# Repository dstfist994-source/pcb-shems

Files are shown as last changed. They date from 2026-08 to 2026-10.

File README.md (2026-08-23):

# Industrial IoT Smart Edge Device & Isolated Energy Controller

**A robust, mixed-signal hardware platform designed for AC mains energy monitoring, power conversion, and isolated load control. Engineered with high-voltage clearance, discrete signal shifting, and inductive load protection.**

---

## 📖 Overview

This **Smart Edge Node** is an industrial/home energy monitoring and switching board that bridges high-voltage AC mains power with low-voltage microcontroller logic. Designed with a focus on **analog hardware reliability**, **power distribution**, and **galvanic isolation**, the design integrates on-board AC-DC regulated conversion, discrete MOSFET level translation, and an optoisolated transistor relay driver with flyback suppression.

The system utilizes an **ESP8266 (Lolin)** for edge processing and software-driven UART communication with a **PZEM-004T** metering module, enabling real-time telemetry publication over Wi-Fi (MQTT/HTTP) while safely controlling heavy AC electrical loads.

---

## 📸 Visuals

| **3D PCB Render** | **PCB Layout & Routing** | **Hardware Schematic** |
|:---:|:---:|:---:|
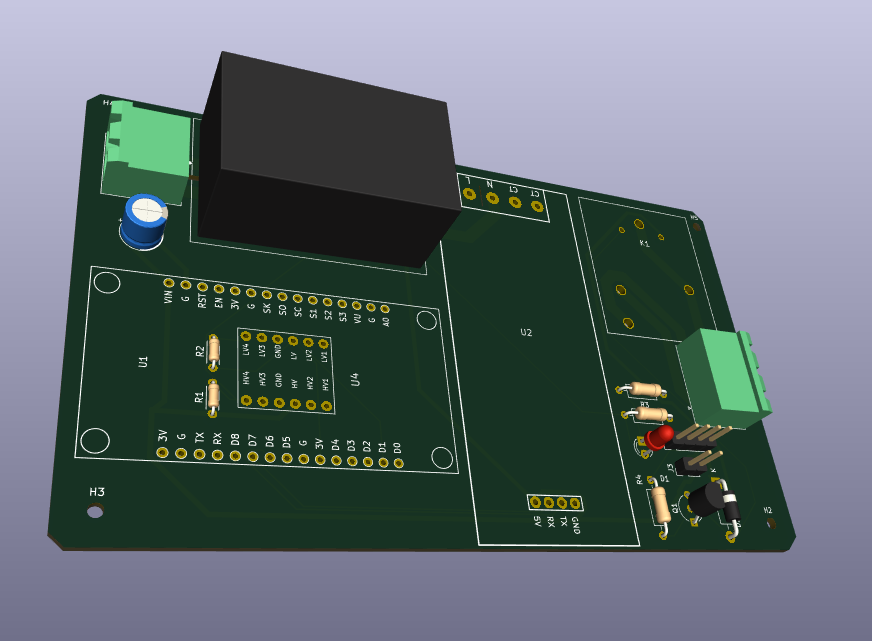
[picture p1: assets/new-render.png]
3D Render
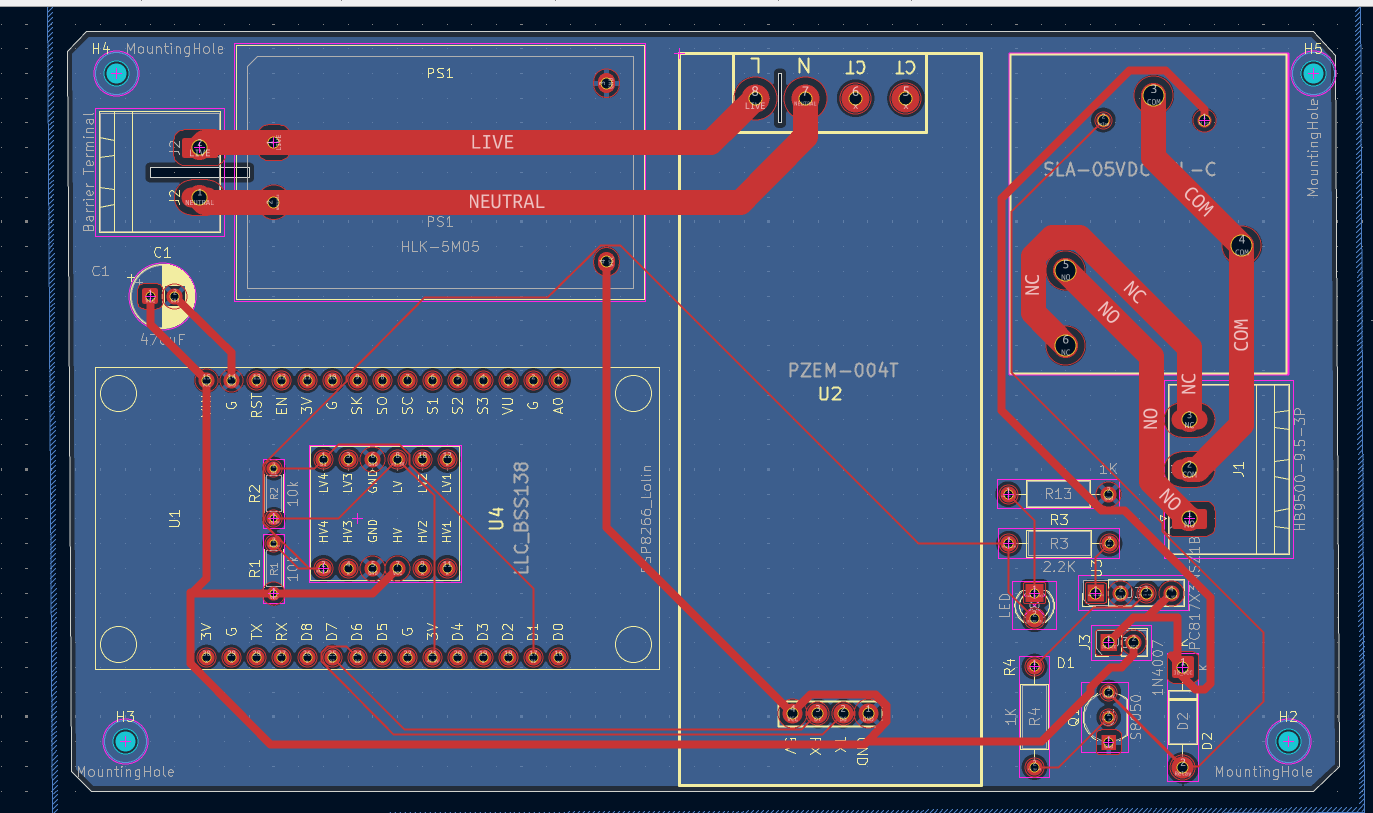
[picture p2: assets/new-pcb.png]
PCB Layout
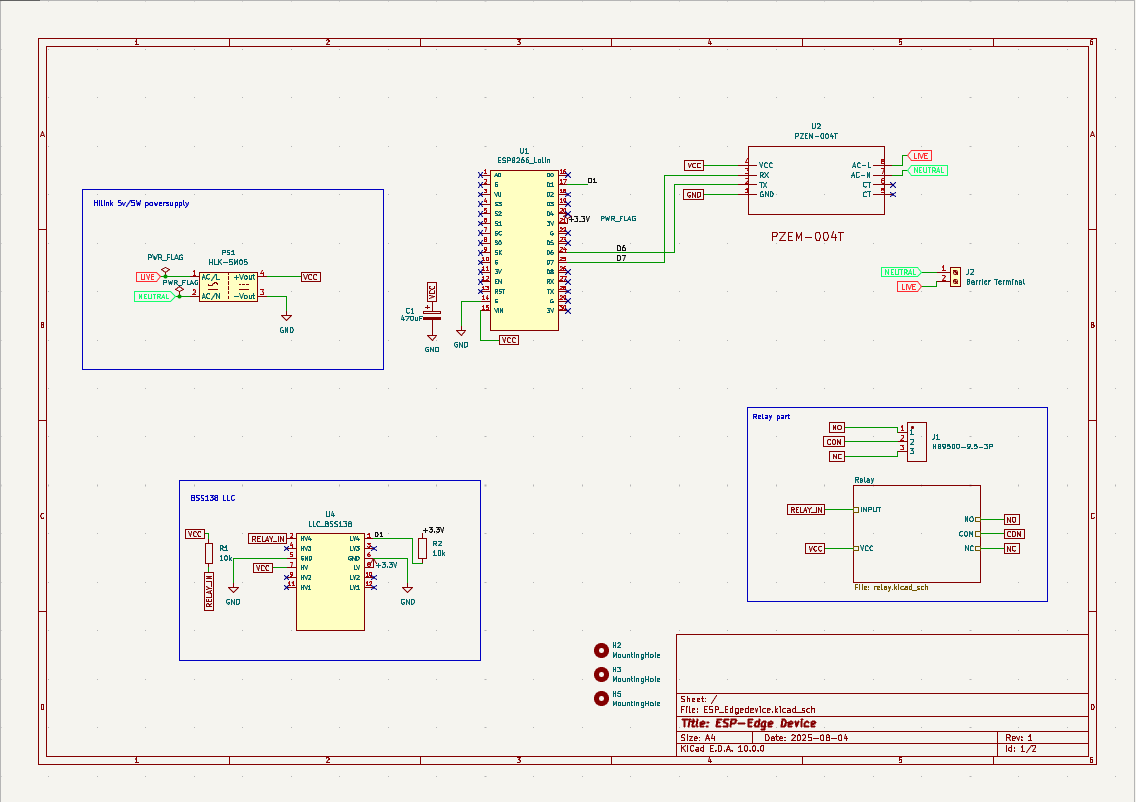
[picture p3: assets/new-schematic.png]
Schematic
|  |  |  |
| *KiCad 3D Ray-traced Board View* | *2-Layer Trace & High-Voltage Clearance* | *System Schematic Architecture* |

---

## ⚡ Hardware & Analog Engineering Highlights

### 1. Power Management & Bulk Decoupling
* **Integrated AC-DC Conversion:** Employs an on-board **Hi-Link HLK-5M05** module to convert $230\text{V AC}$ mains input directly down to a regulated $5\text{V DC}$ supply rail.
* **Transient Suppression & Ripple Filtering:** Features a high-capacity **$470\ \mu\text{F}$ bulk electrolytic capacitor ($C1$)** across the $5\text{V}$ rail to absorb voltage dips, suppress power supply ripple, and maintain rail stability during high instantaneous relay coil pull-in current.

### 2. Level Translation & Signal Integrity
* **Bi-Directional MOSFET Level Shifting:** Incorporates a discrete **BSS138 N-channel MOSFET Logic Level Converter ($U4$)** to bridge the $3.3\text{V CMOS}$ GPIO output of the ESP8266 ($D1$) to the $5\text{V TTL}$ driver logic without overdriving MCU input pins.
* **Isolated UART Interface:** Software Serial UART interface ($D6/D7$) connecting to the **PZEM-004T** energy metering frontend for accurate RMS Voltage, Current, Active Power, Frequency, and Power Factor acquisition.

### 3. Optoisolated Load Control & Inductive Suppression
* **Galvanic Isolation Drive Stage:** High-voltage AC switching is completely isolated from low-voltage digital control using a **PC817 Optocoupler** and an **S8050 NPN transistor** driver stage.
* **Back-EMF Inductive Protection:** A **1N4007 flyback suppression diode ($D1$)** is placed across the **SLA-05VDC** relay coil to clamp high-voltage inductive spikes generated during coil de-energization, protecting switching silicon from overshoot breakdown.
* **Visual Diagnostics:** Integrated LED indicator with current-limiting resistor ($1\text{ k}\Omega$) for visual relay status feedback.

### 4. High-Voltage PCB Layout & Safety Design
* **Creepage & Clearance:** Wide physical clearance and routing separation between the $230\text{V}$ AC mains region (Live/Neutral) and low-voltage $5\text{V}/3.3\text{V}$ DC signal planes to prevent electrical arcing.
* **Current-Handling Traces:** Heavy trace widths utilized on AC Live/Neutral routing and high-current relay switching paths to minimize trace impedance, drop, and thermal rise under heavy electrical load.

---

## 🛠 Subsystem Breakdown

| Subsystem | Circuitry / Components | Function |
| :--- | :--- | :--- |
| **Power Supply** | HLK-5M05 + $470\ \mu\text{F}$ Capacitor | AC-DC Step-down ($230\text{V AC} \to 5\text{V DC}$) & Rail Filtering |
| **Microcontroller** | ESP8266 (Lolin V3 Footprint) | Wireless Telemetry, MQTT, SoftSerial UART, GPIO Control |
| **Logic Level Conversion** | BSS138 MOSFET Level Shifter ($U4$) | $3.3\text{V} \leftrightarrow 5\text{V}$ Logic Level Translation |
| **Relay Driver** | PC817 Optocoupler + S8050 NPN + 1N4007 Diode | Isolated coil energization & Back-EMF suppression |
| **AC Load Control** | SLA-05VDC High-Power Relay | Heavy AC Load ON/OFF Disconnect |
| **Energy Measurement** | PZEM-004T AC Sensor | High-accuracy RMS Voltage, Current, & Power Telemetry |

---

## 👨‍💻 Authors

- **Suvam Seth**
  *Power Engineering Student | PCB Design | Analog Electronics & Systems Design*

- **Sarin Sanyal**
  *Power Engineering Student | Analog & Mixed-Signal Circuit Design | Embedded Hardware | AI*

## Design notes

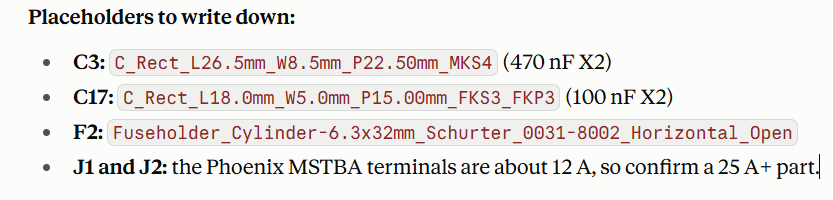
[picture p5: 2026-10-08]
assets/placeholders.png

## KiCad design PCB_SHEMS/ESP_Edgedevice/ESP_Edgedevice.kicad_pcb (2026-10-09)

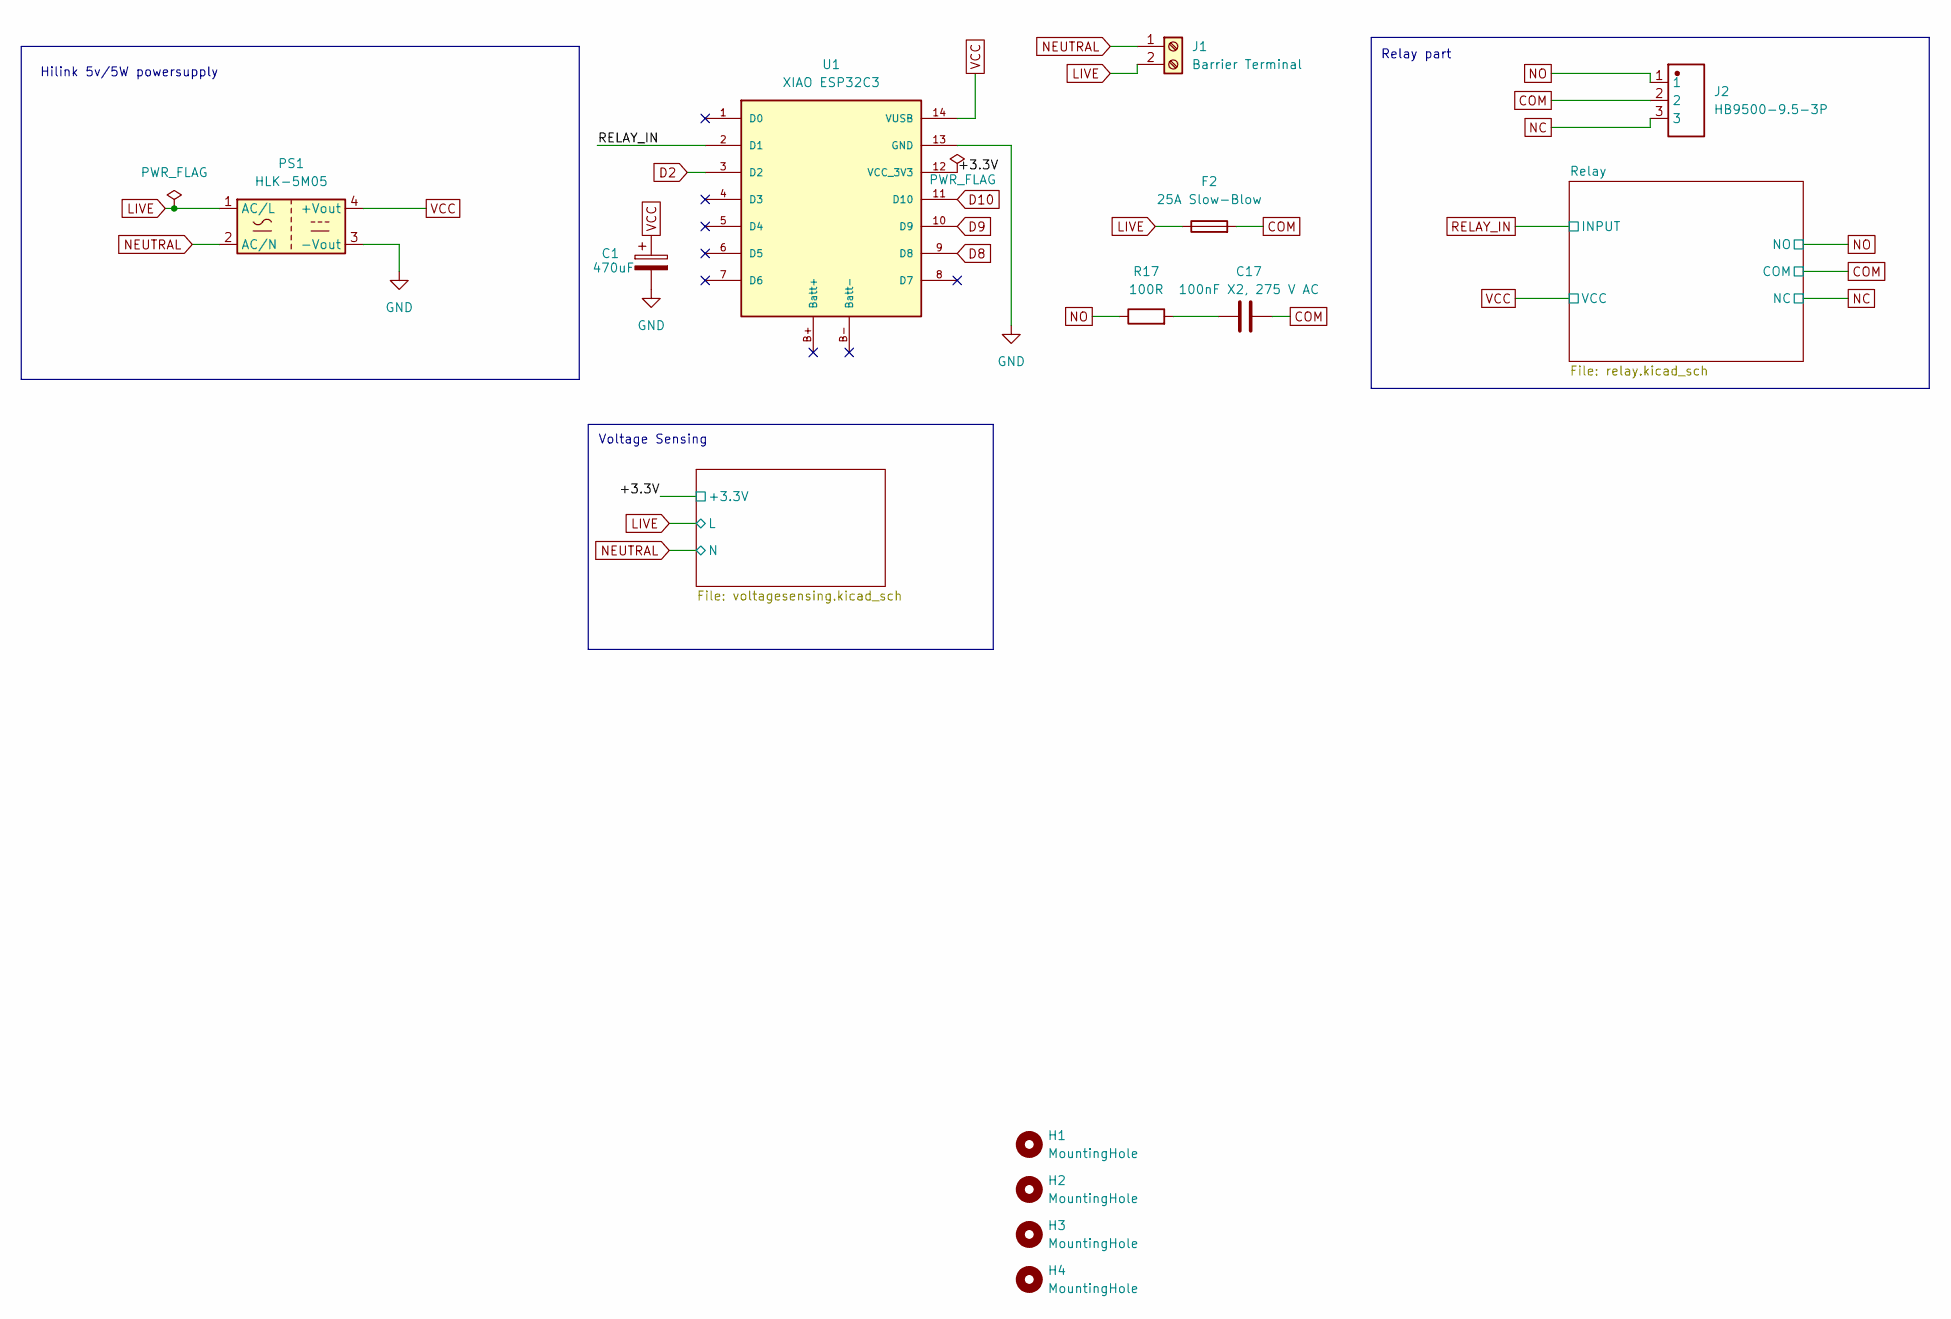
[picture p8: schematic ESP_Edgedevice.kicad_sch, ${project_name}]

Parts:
C1: 470uF; CP_Radial_D6.3mm_P2.50mm
C17: 100nF X2, 275 V AC; C_Rect_L18.0mm_W5.0mm_P15.00mm_FKS3_FKP3
F2: 25A Slow-Blow; Fuseholder_Cylinder-6.3x32mm_Schurter_0031-8002_Horizontal_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
H1, H2, H3, H4: MountingHole; MountingHole_2.1mm
J1: Barrier Terminal; PhoenixContact_MSTBA_2,5_2-G_1x02_P5.00mm_Horizontal
J2: HB9500-9.5-3P; HB9500_9.5-3P; Manufacturer Part HB9500-9.5-3P
PS1: HLK-5M05; Converter_ACDC_Hi-Link_HLK-5Mxx
R17: 100R; R_Axial_DIN0309_L9.0mm_D3.2mm_P12.70mm_Horizontal
U1: XIAO ESP32C3; XIAO_Socket_W15.24

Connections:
/+3.3V: U1.12 (VCC_3V3); also elsewhere on the board
COM: C17.2, F2.2, J2.2; also elsewhere on the board
D2: U1.3 (D2); also elsewhere on the board
D8: U1.9 (D8); also elsewhere on the board
D9: U1.10 (D9); also elsewhere on the board
D10: U1.11 (D10); also elsewhere on the board
GND: C1.2, PS1.3 (-Vout), U1.13 (GND); also elsewhere on the board
LIVE: F2.1, J1.2, PS1.1 (AC/L); also elsewhere on the board
NC: J2.3; also elsewhere on the board
NEUTRAL: J1.1, PS1.2 (AC/N); also elsewhere on the board
NO: J2.1, R17.1; also elsewhere on the board
unnamed: C17.1, R17.2
RELAY_IN: U1.2 (D1); also elsewhere on the board
VCC: C1.1, PS1.4 (+Vout), U1.14 (VUSB); also elsewhere on the board

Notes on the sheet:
Voltage Sensing
Relay part
Hilink 5v/5W powersupply

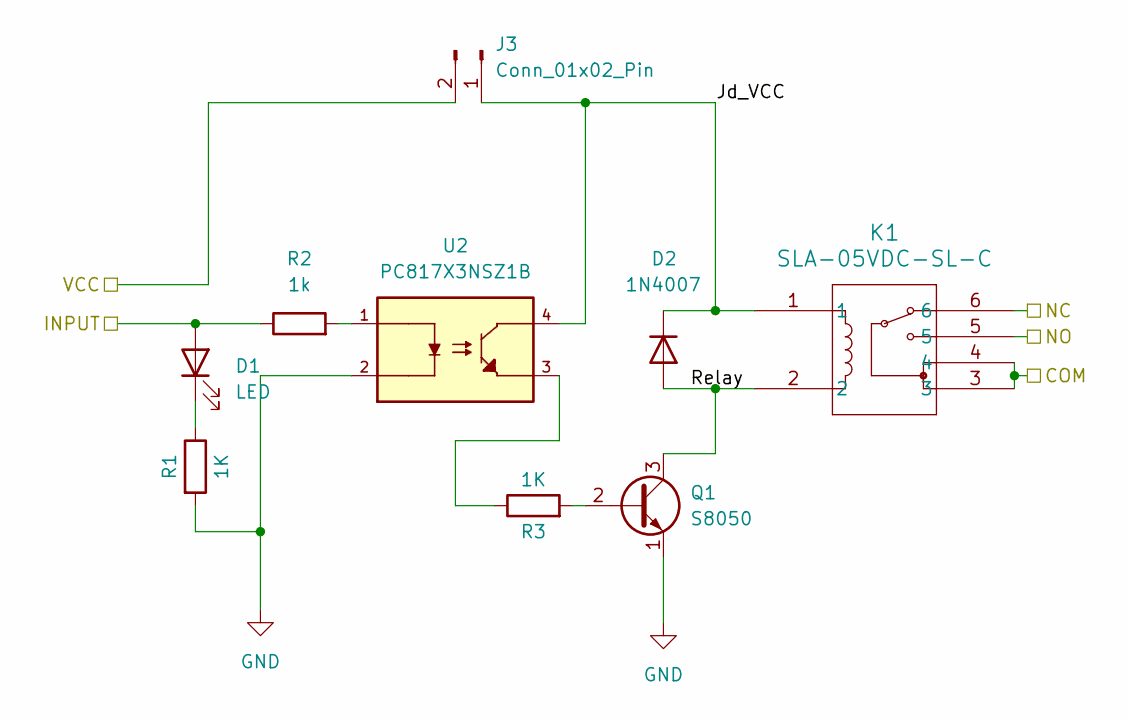
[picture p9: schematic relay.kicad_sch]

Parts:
D1: LED; LED_D3.0mm
D2: 1N4007; D_DO-41_SOD81_P10.16mm_Horizontal
J3: Conn_01x02_Pin; PinHeader_1x02_P2.54mm_Vertical
K1: SLA-05VDC-SL-C; RELAY-TH_SLA-XXVDC-XX-C
Q1: S8050; TO-92_Inline_Wide
R1, R3: 1K; R_1206_3216Metric
R2: 1k; R_1206_3216Metric
U2: PC817X3NSZ1B; DIP-4_W7.62mm; PARTREV October 7, 2016

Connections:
/Relay/Jd_VCC: D2.1 (K), J3.1, K1.1, U2.4
/Relay/Relay: D2.2 (A), K1.2, Q1.3 (C)
COM: K1.3, K1.4; also elsewhere on the board
GND: Q1.1 (E), R1.2, U2.2; also elsewhere on the board
NC: K1.6; also elsewhere on the board
NO: K1.5; also elsewhere on the board
unnamed: D1.1 (K), R1.1
unnamed: Q1.2 (B), R3.2
unnamed: R2.2, U2.1
unnamed: R3.1, U2.3
RELAY_IN: D1.2 (A), R2.1; also elsewhere on the board
VCC: J3.2; also elsewhere on the board

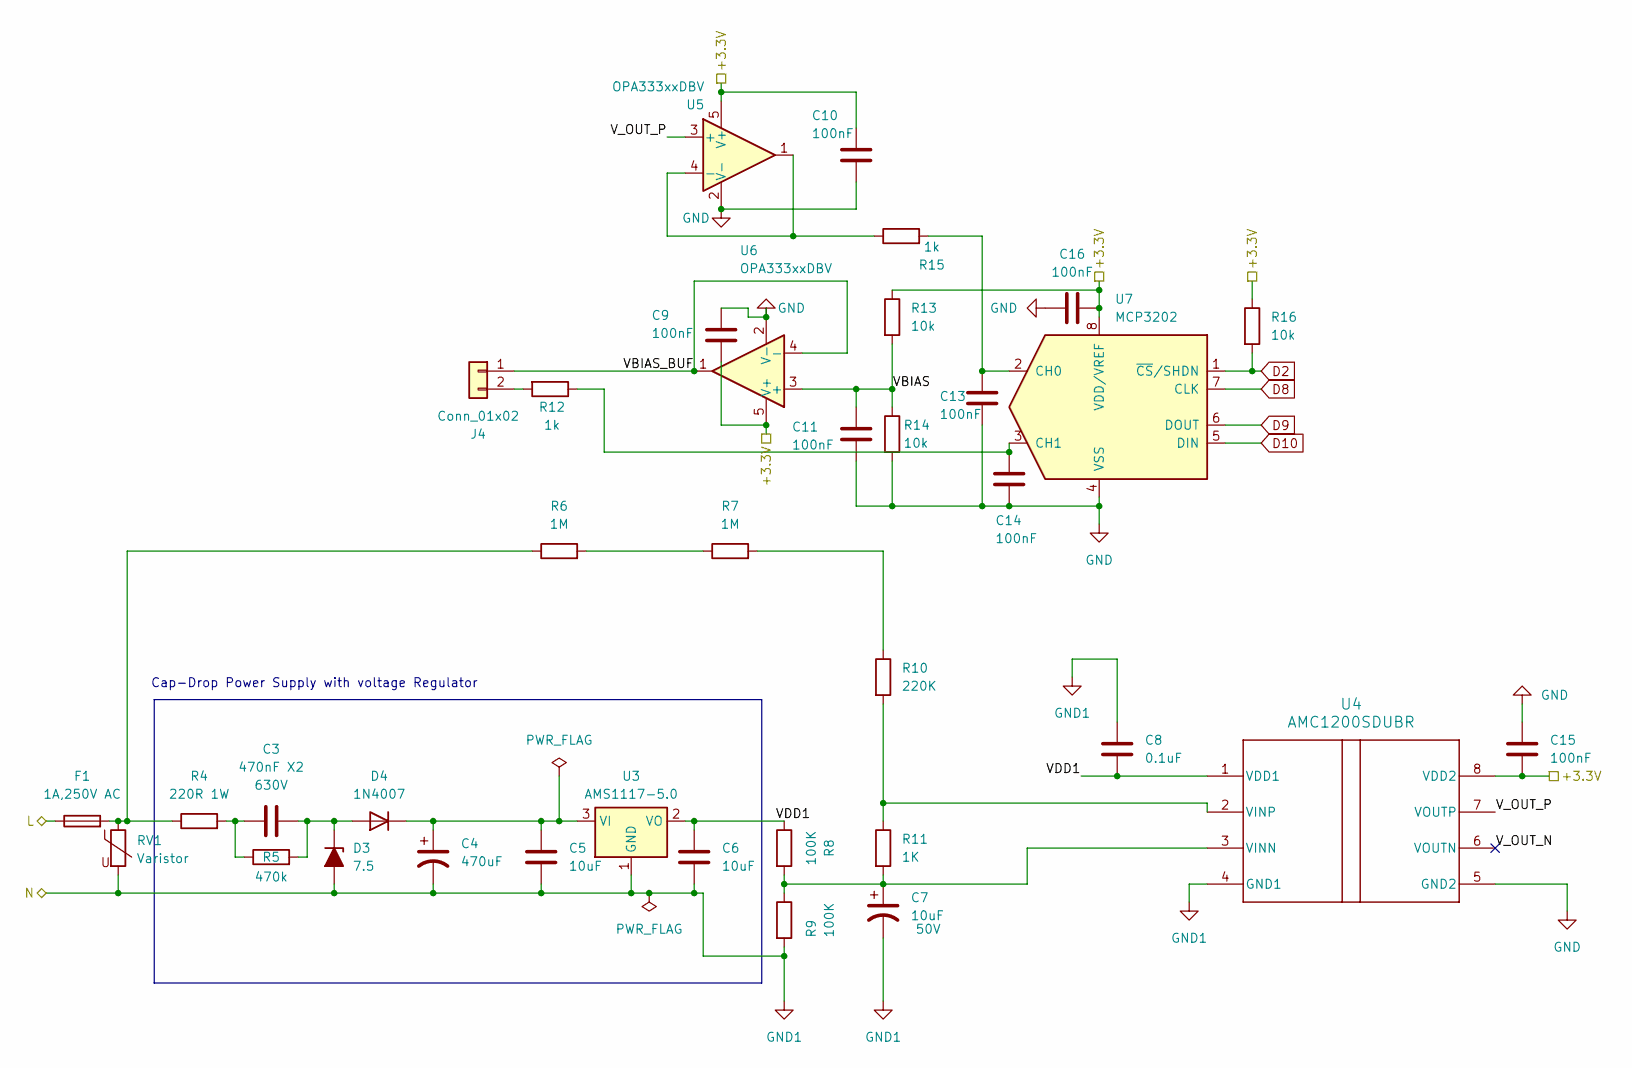
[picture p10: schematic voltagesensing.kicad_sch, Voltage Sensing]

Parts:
C3: 470nF X2; C_Rect_L26.5mm_W8.5mm_P22.50mm_MKS4; voltage 630V
C4: 470uF; CP_Radial_D10.0mm_P5.00mm
C5: 10uF; C_1206_3216Metric
C6: 10uF; CP_Radial_D5.0mm_P2.50mm
C7: 10uF; CP_Radial_D5.0mm_P2.50mm; Voltage 50V
C8: 0.1uF; C_1206_3216Metric
C9, C10, C11, C13, C14, C15, C16: 100nF; C_1206_3216Metric
D3: 7.5; D_MiniMELF
D4: 1N4007; D_DO-41_SOD81_P10.16mm_Horizontal
F1: 1A,250V AC; Fuseholder_Cylinder-5x20mm_Schurter_0031_8201_Horizontal_Op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
J4: Conn_01x02; PinHeader_1x02_P2.54mm_Vertical
R4: 220R 1W; R_Axial_DIN0414_L11.9mm_D4.5mm_P15.24mm_Horizontal
R5: 470k; R_Axial_DIN0207_L6.3mm_D2.5mm_P10.16mm_Horizontal
R6, R7: 1M; R_Axial_DIN0207_L6.3mm_D2.5mm_P10.16mm_Horizontal
R8, R9: 100K; R_1206_3216Metric
R10: 220K; R_1206_3216Metric
R11: 1K; R_1206_3216Metric
R12, R15: 1k; R_1206_3216Metric
R13, R14, R16: 10k; R_1206_3216Metric
RV1: Varistor; RV_Disc_D12mm_W4.2mm_P7.5mm
U3: AMS1117-5.0; SOT-223-3_TabPin2
U4: AMC1200SDUBR; DUB0008A-IPC_A
U5, U6: OPA333xxDBV; SOT-23-5
U7: MCP3202; TSSOP-8_4.4x3mm_P0.65mm

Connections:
/+3.3V: C9.1, C10.2, C15.2, C16.1, R13.1, R16.1, U4.8 (VDD2), U5.5 (V+), U6.5 (V+), U7.8 (VDD/VREF); also elsewhere on the board
/voltagesensing.kicad_sch/VBIAS: C11.1, R13.2, R14.1, U6.3 (+)
/voltagesensing.kicad_sch/VBIAS_BUF: J4.1, U6.1, U6.4 (-)
/voltagesensing.kicad_sch/VDD1: C6.1, C8.2, R8.1, U3.2 (VO), U4.1 (VDD1)
/voltagesensing.kicad_sch/V_OUT_N: U4.6 (VOUTN)
/voltagesensing.kicad_sch/V_OUT_P: U4.7 (VOUTP), U5.3 (+)
D2: R16.2, U7.1 (~CS/SHDN); also elsewhere on the board
D8: U7.7 (CLK); also elsewhere on the board
D9: U7.6 (DOUT); also elsewhere on the board
D10: U7.5 (DIN); also elsewhere on the board
GND: C9.2, C10.1, C11.2, C13.2, C14.2, C15.1, C16.2, R14.2, U4.5 (GND2), U5.2 (V-), U6.2 (V-), U7.4 (VSS); also elsewhere on the board
LIVE: F1.1; also elsewhere on the board
NEUTRAL: C4.2, C5.2, C6.2, C7.2, C8.1, D3.2 (A), R9.2, RV1.2, U3.1 (GND), U4.4 (GND1); also elsewhere on the board
unnamed: C3.1, R4.2, R5.1
unnamed: C3.2, D3.1 (K), D4.2 (A), R5.2
unnamed: C4.1, C5.1, D4.1 (K), U3.3 (VI)
unnamed: F1.2, R4.1, R6.1, RV1.1
unnamed: J4.2, R12.2
unnamed: R6.2, R7.1
unnamed: R7.2, R10.1
unnamed: C7.1, R8.2, R9.1, R11.2, U4.3 (VINN)
unnamed: R10.2, R11.1, U4.2 (VINP)
unnamed: R15.1, U5.1, U5.4 (-)
unnamed: C13.1, R15.2, U7.2 (CH0)
unnamed: C14.1, R12.1, U7.3 (CH1)

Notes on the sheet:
Cap-Drop Power Supply with voltage Regulator

Board: 2 copper layers, 57 parts (0 on the bottom side), 36 nets, no tracks yet.

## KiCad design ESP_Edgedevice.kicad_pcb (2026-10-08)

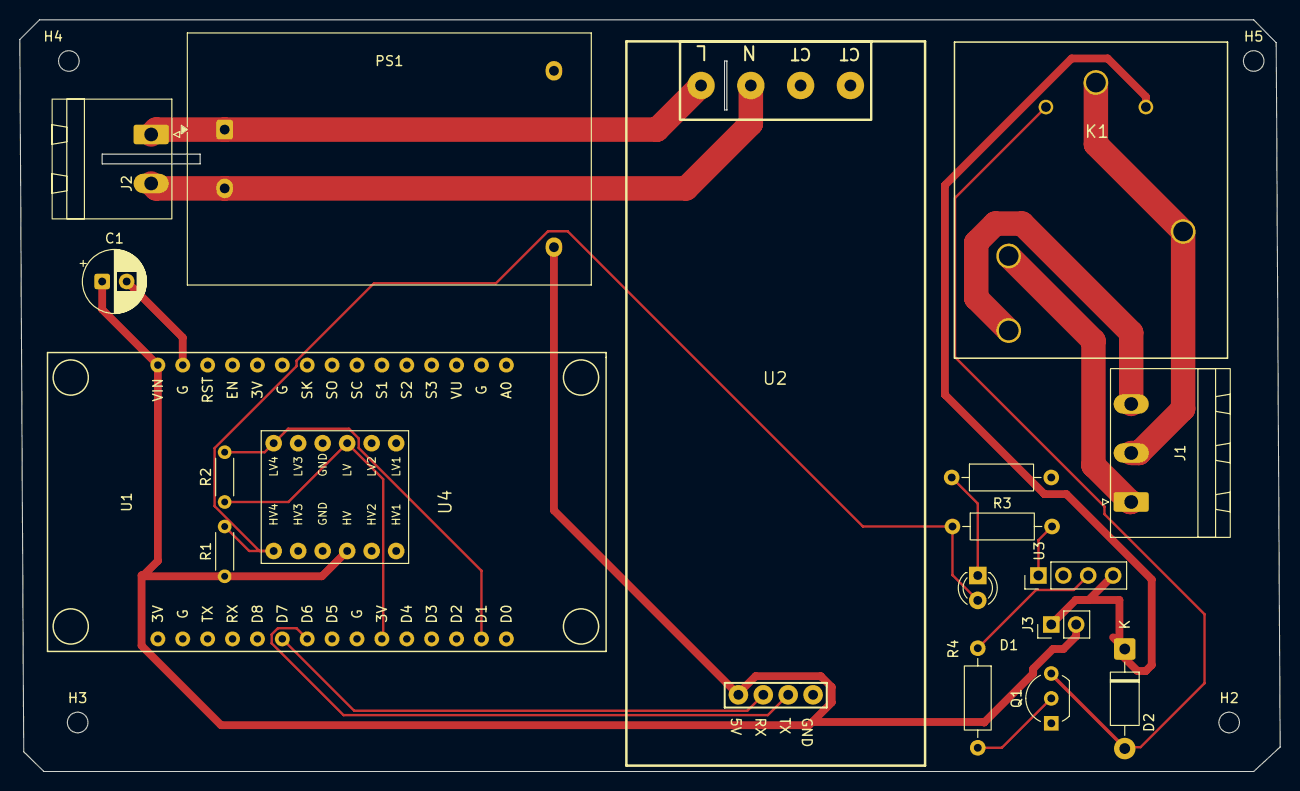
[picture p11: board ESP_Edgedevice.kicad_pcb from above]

Board: 2 copper layers, 128.6 x 76.7 mm, 22 parts (0 on the bottom side), 18 nets.

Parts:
C1: 470uF; CP_Radial_D6.3mm_P2.50mm
D1: LED; LED_D3.0mm
D2: 1N4007; D_DO-41_SOD81_P10.16mm_Horizontal
H2, H3, H4, H5: MountingHole; MountingHole_2.1mm
J1: HB9500-9.5-3P; PhoenixContact_MSTBA_2,5_3-G_1x03_P5.00mm_Horizontal
J2: Barrier Terminal; PhoenixContact_MSTBA_2,5_2-G_1x02_P5.00mm_Horizontal
J3: Conn_01x02_Pin; PinHeader_1x02_P2.54mm_Vertical
K1: SLA-05VDC-SL-C; K_SLA_C_NFR
PS1: HLK-5M05; Converter_ACDC_Hi-Link_HLK-5Mxx
Q1: S8050; TO-92_Inline_Wide
R1, R2: 10k; R_Axial_DIN0204_L3.6mm_D1.6mm_P5.08mm_Horizontal
R3: 2.2K; R_Axial_DIN0207_L6.3mm_D2.5mm_P10.16mm_Horizontal
R4, R13: 1K; R_Axial_DIN0207_L6.3mm_D2.5mm_P10.16mm_Horizontal
U1: ESP8266_Lolin; NodeMCU-LoLinV3
U2: PZEM-004T; PZEM-004T_V3
U3: PC817X3NSZ1B; PinHeader_1x04_P2.54mm_Vertical
U4: LLC_BSS138

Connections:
+3.3V: R2.1, U1.21 (3V), U4.8 (LV)
/D1: R2.2, U1.17 (D1), U4.1 (LV4)
/D6: U1.24 (D6), U2.2 (TX)
/D7: U1.25 (D7), U2.3 (RX)
/Relay/Jd_VCC: D2.1 (K), J3.1, K1.1, U3.4
/Relay/Relay: D2.2 (A), K1.2, Q1.3 (C)
COM: J1.2, K1.3, K1.4
GND: C1.2, PS1.3 (-Vout), Q1.1 (E), R13.2, U1.14 (G), U2.1 (GND), U3.2, U4.5 (GND), U4.6 (GND)
LIVE: J2.2, PS1.1 (AC/L), U2.8 (AC-L)
NC: J1.3, K1.6
NEUTRAL: J2.1, PS1.2 (AC/N), U2.7 (AC-N)
NO: J1.1, K1.5
unnamed: D1.1 (K), R13.1
unnamed: Q1.2 (B), R4.2
unnamed: R3.2, U3.1
unnamed: R4.1, U3.3
RELAY_IN: D1.2 (A), R1.2, R3.1, U4.2 (HV4)
VCC: C1.1, J3.2, PS1.4 (+Vout), R1.1, U1.15 (VIN), U2.4 (VCC), U4.7 (HV)

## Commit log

2026-08-23 new commit
    [ESP_Edgedevice.kicad_pcb, ESP_Edgedevice.kicad_sch, relay.kicad_sch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]
2026-10-08 added ADC, next changes are left
    [ESP_Edgedevice.kicad_pcb, ESP_Edgedevice.kicad_sch, relay.kicad_sch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]
2026-10-08 major changes made to schematics
    [ESP_Edgedevice.kicad_sch, relay.kicad_sch, voltagesensing.kicad_sch]
2026-10-08 PCB left
    [ESP_Edgedevice.kicad_pcb, ESP_Edgedevice.kicad_sch, relay.kicad_sch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]
2026-10-08 more changes midnight
    [ESP_Edgedevice.kicad_pcb, ESP_Edgedevice.kicad_sch]
2026-10-09 made more Schema changes in Lab
    [ESP_Edgedevice.kicad_pcb, ESP_Edgedevice.kicad_sch, relay.kicad_sch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]
2026-10-09 PCB update
